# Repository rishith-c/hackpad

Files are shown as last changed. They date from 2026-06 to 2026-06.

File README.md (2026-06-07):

# Hackpad

A 12-key macropad with a rotary encoder and an OLED display, built on a
Seeed XIAO RP2040 and running KMK firmware. Submitted to Hack Club's
[Hackpad](https://hackpad.hackclub.com) You Ship, We Ship program.

**v2** — the most loaded build that fits the Hackpad rules at once:
12 MX keys, 1 EC11 rotary encoder, 1 OLED display, and every usable GPIO
on the XIAO consumed (11 / 11). 13 inputs, well under the 16-input cap;
95 × 95 mm board, well inside the 100 × 100 mm size cap.

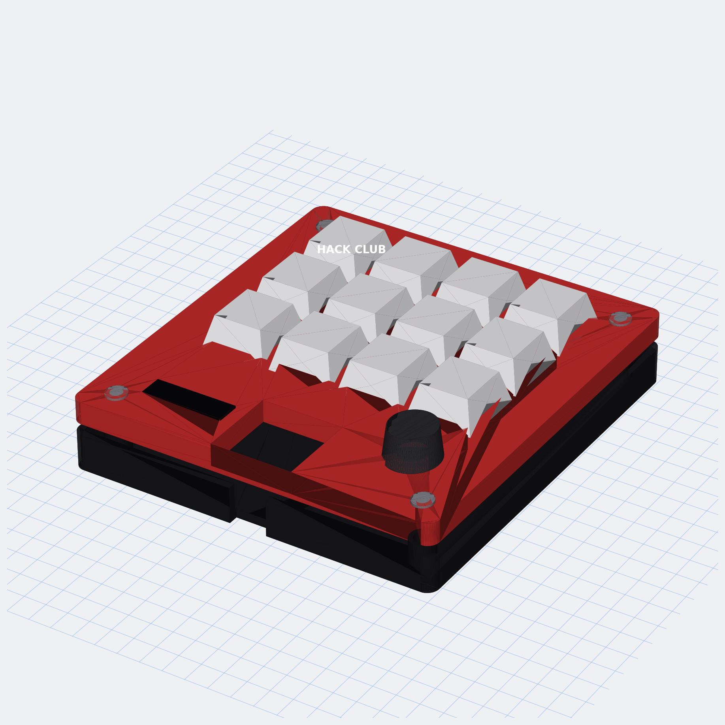
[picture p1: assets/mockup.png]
Assembled mockup


## Features

- **12 MX mechanical switches** in a 4 × 3 diode matrix (COL2ROW, 1N4148)
- **1 EC11 rotary encoder** — defaults to volume +/− (re-mapped per layer)
- **0.91" 128 × 32 SSD1306 OLED** showing the active layer name
- **3 firmware layers** (default / media / numpad), momentary switching
  via the bottom-right key (and bottom-right-2 for L2)
- **Two-part 3D-printed case** (red top plate + black bottom tray),
  M3 heatset insert bosses, USB-C side cutout
- **Individual STL part files** for every printable AND hardware item
  (top, bottom, M3 screws, heatset inserts)

## CAD model

Full assembled view in [`cad/assembled-model.step`](cad/assembled-model.step) —
GitHub renders the STEP inline. STL version in
[`cad/assembled-model.stl`](cad/assembled-model.stl).

Printable + hardware parts (all generated by
[`build_scripts/build_case.py`](build_scripts/build_case.py)):

| Part | STL | STEP | Notes |
|---|---|---|---|
| Top plate (red, 5 mm) | [Top.stl](production/Top.stl) | [Top.step](production/Top.step) | 12 MX cutouts + encoder hole + OLED window + XIAO inspection |
| Bottom tray (black, 8 mm) | [Bottom.stl](production/Bottom.stl) | [Bottom.step](production/Bottom.step) | 4× heatset bosses + USB-C side cutout |
| M3 × 16 mm SHCS screw (×4) | [M3x16_Screw.stl](production/M3x16_Screw.stl) | [M3x16_Screw.step](production/M3x16_Screw.step) | hardware visualization — kit supplies real ones |
| M3 × 5 × 4 mm brass heatset insert (×4) | [HeatsetInsert_M3x5x4.stl](production/HeatsetInsert_M3x5x4.stl) | [HeatsetInsert_M3x5x4.step](production/HeatsetInsert_M3x5x4.step) | hardware visualization — kit supplies real ones |

Case fits within **99 × 99 × 15 mm** — well inside Hackpad's
200 × 200 × 100 mm limit. Screwed together with 4 × M3 × 16 mm SHCS bolts
into M3 × 5 × 4 mm brass heatset inserts.

## PCB

Built in [KiCad 9](https://www.kicad.org/) from
[`pcb/hackpad.kicad_pro`](pcb/hackpad.kicad_pro). The whole board is
generated programmatically by
[`build_scripts/build_pcb.py`](build_scripts/build_pcb.py) from the netlist
+ placement CSVs — re-running it reproduces the `.kicad_pcb` byte-for-byte.

Schematic:

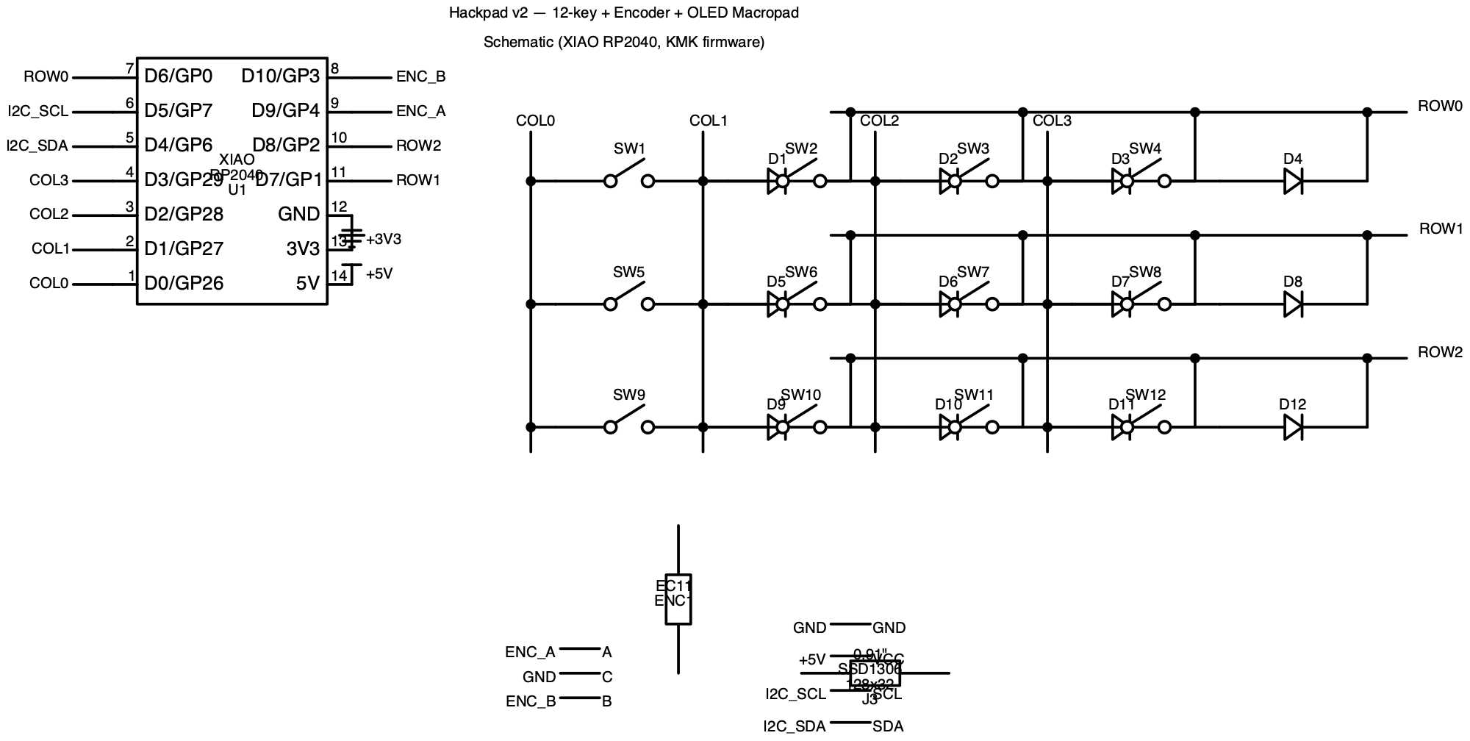
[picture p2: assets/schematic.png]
Schematic


PCB layout (top and bottom copper):

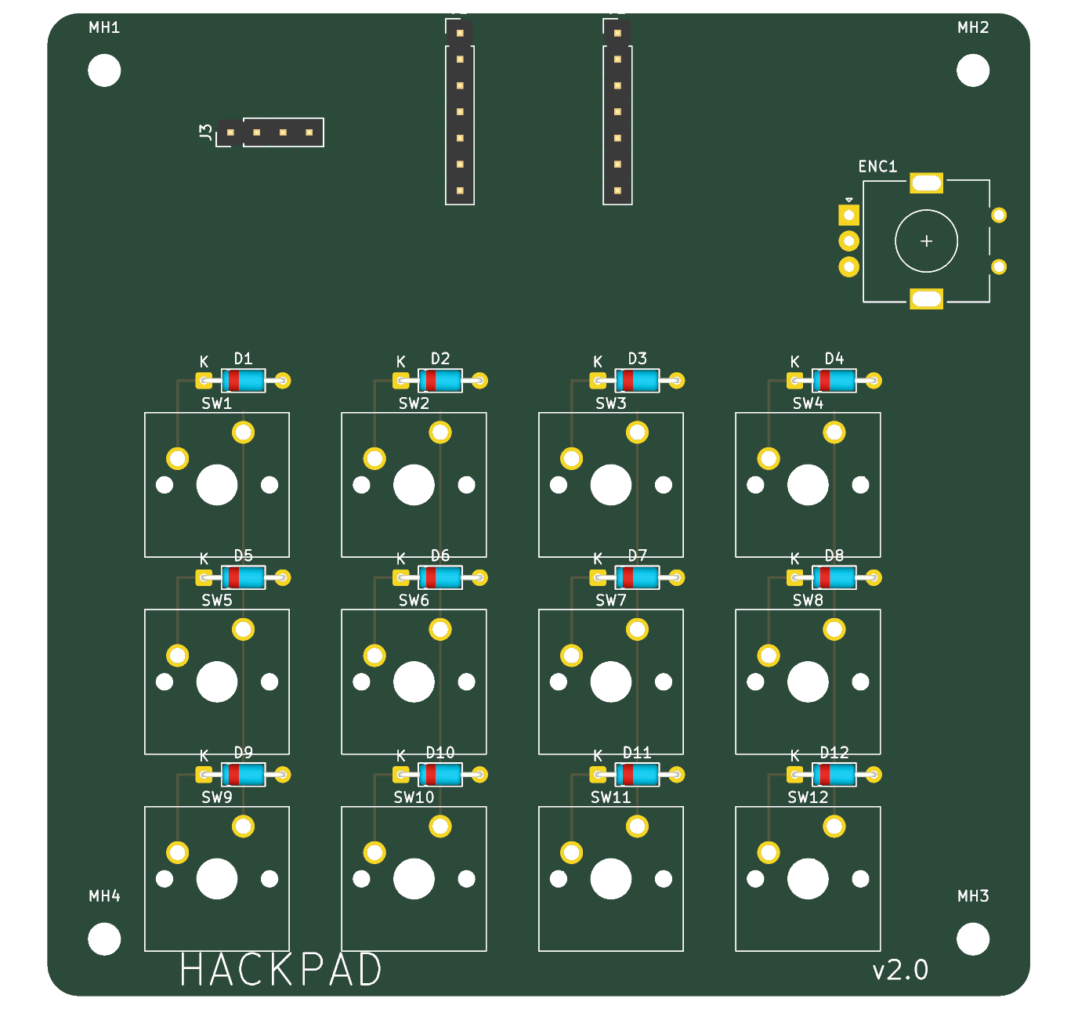
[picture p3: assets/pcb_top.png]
PCB top

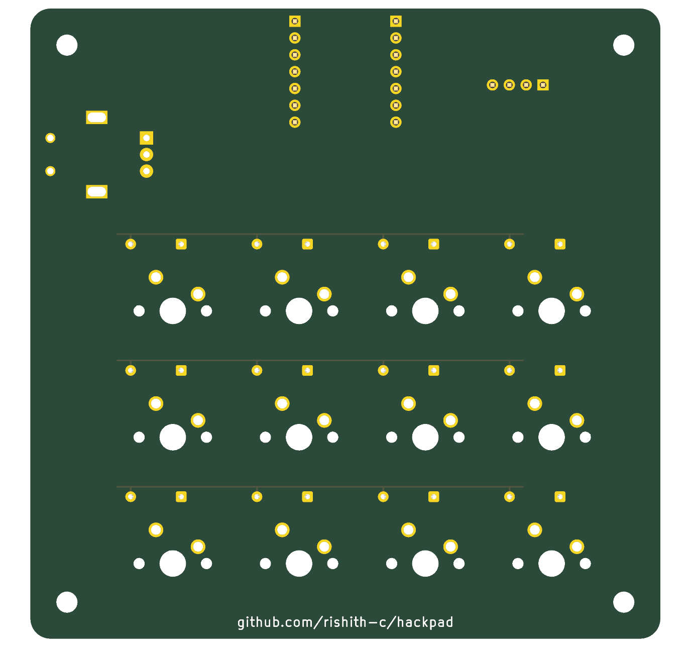
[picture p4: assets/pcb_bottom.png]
PCB bottom


- **Dimensions:** 95 × 95 mm (within the Hackpad 100 × 100 mm rule)
- **Layers:** 2 (F.Cu signal trunks + B.Cu GND pour and ROW trunks)
- **OLED header pin order:** GND – VCC – SCL – SDA (kit spec)
- **Footprints:** Cherry MX 1.00u PCB, 1N4148 DO-35 horizontal,
  EC11E vertical, XIAO on 2 × `PinHeader_1x07_P2.54mm_Vertical`,
  OLED on `PinHeader_1x04_P2.54mm_Vertical`, `MountingHole_3.2mm_M3`
- **Routing:** matrix is fully routed in copper (4 COL trunks F.Cu,
  3 ROW trunks B.Cu with cathode tabs, 12 switch→anode bridges, GND
  pour). 11 short XIAO ↔ peripheral signal pulls (4 COL + 3 ROW + SDA
  + SCL + 5V + ENC_A + ENC_B) are left as ratlines for ~5 min of
  interactive routing — see
  [`pcb/HOW_TO_FINISH.md`](pcb/HOW_TO_FINISH.md) for the exact
  start/end coordinates of each pull.
- **Silkscreen:** `HACKPAD v2.0` on the front, `github.com/rishith-c/hackpad`
  on the back.
- **DRC:** passes at error level
  (`kicad-cli pcb drc --severity-error` → **0 violations**)

Gerbers exported and ready for JLCPCB:
[`production/gerbers.zip`](production/gerbers.zip).
Order at 2 layers · 1.6 mm · HASL · green.

## Firmware

KMK (CircuitPython). See [`firmware/README.md`](firmware/README.md) for
flashing instructions. Sources in [`firmware/KMK/`](firmware/KMK/):

| File | Purpose |
|---|---|
| [`firmware/KMK/main.py`](firmware/KMK/main.py) | 4×3 matrix + encoder + OLED setup, 3 keymap layers |
| [`firmware/KMK/code.py`](firmware/KMK/code.py) | CircuitPython entry point (imports `main`) |
| [`firmware/KMK/boot.py`](firmware/KMK/boot.py) | disables CIRCUITPY auto-reload while plugged in |

## Pin map

The XIAO RP2040 exposes 11 usable GPIO. **All 11 are used.**

| XIAO | GPIO | Role |
|---|---|---|
| D0 | GP26 | matrix COL0 (left column) |
| D1 | GP27 | matrix COL1 |
| D2 | GP28 | matrix COL2 |
| D3 | GP29 | matrix COL3 (right column) |
| D4 | GP6 | OLED SDA (I²C1) |
| D5 | GP7 | OLED SCL (I²C1) |
| D6 | GP0 | matrix ROW0 (top row) |
| D7 | GP1 | matrix ROW1 (middle row) |
| D8 | GP2 | matrix ROW2 (bottom row) |
| D9 | GP4 | encoder phase A |
| D10 | GP3 | encoder phase B |

No spare GPIOs. See [`pcb/DESIGN_NOTES.md`](pcb/DESIGN_NOTES.md) for
alternate firmware tweaks (drop OLED for encoder push + RGB; shrink
matrix to 3×3 for a second encoder; etc.) — each one reuses this same
PCB without changes.

## Bill of Materials

See [`production/BOM.csv`](production/BOM.csv). Everything except the
PLA filament is in the Hackpad kit.

- 1 × Seeed XIAO RP2040 (through-hole, mounts on 2 × 1×7 pin sockets)
- 12 × Cherry MX mechanical switch
- 12 × DSA blank keycap
- 12 × 1N4148 diode (DO-35)
- 1 × EC11 rotary encoder (A/B wired, push left unwired)
- 1 × 0.91" SSD1306 128 × 32 OLED (I²C, addr 0x3C, pin order GND-VCC-SCL-SDA)
- 4 × M3 × 16 mm SHCS bolt
- 4 × M3 × 5 × 4 mm brass heatset insert
- 1 × 3D-printed top plate ([`production/Top.stl`](production/Top.stl))
- 1 × 3D-printed bottom tray ([`production/Bottom.stl`](production/Bottom.stl))

## Repository layout

```
├── README.md
├── LICENSE
├── cad/
│   ├── assembled-model.step              # full assembly (Hackpad spec)
│   └── assembled-model.stl               # same, STL (GitHub interactive viewer)
├── pcb/
│   ├── hackpad.kicad_pro                 # KiCad project
│   ├── hackpad.kicad_sch                 # schematic stub (canonical viz in assets/schematic.png)
│   ├── hackpad.kicad_pcb                 # placed + matrix-routed board
│   ├── netlist.csv                       # canonical net list
│   ├── placement.csv                     # per-part X/Y/rotation
│   ├── DESIGN_NOTES.md                   # build variants / pin budget reasoning
│   └── HOW_TO_FINISH.md                  # 5-min interactive routing checklist
├── firmware/
│   ├── README.md
│   └── KMK/
│       ├── main.py                       # KMK firmware (matrix + encoder + OLED, 3 layers)
│       ├── code.py                       # CircuitPython entry point
│       └── boot.py                       # boot-time config
├── production/
│   ├── gerbers.zip                       # for JLCPCB (2 layers, 1.6 mm)
│   ├── Top.step / Top.stl                # top plate
│   ├── Bottom.step / Bottom.stl          # bottom tray
│   ├── M3x16_Screw.step / .stl           # individual screw model (used x4)
│   ├── HeatsetInsert_M3x5x4.step / .stl  # individual insert model (used x4)
│   ├── main.py                           # KMK production firmware (copy of firmware/KMK/main.py)
│   ├── BOM.csv                           # bill of materials
│   └── HOW_TO_FINISH.md                  # finish-the-routing checklist
├── assets/                               # README screenshots (PCB top/bottom/iso, mockup, schematic)
└── build_scripts/
    ├── build_pcb.py                      # regenerates pcb/hackpad.kicad_pcb via pcbnew
    ├── build_case.py                     # regenerates production STLs + cad/assembled-model via cadquery
    ├── build_schematic.py                # regenerates assets/schematic.{svg,png} via schemdraw
    └── build_mockup.py                   # regenerates assets/mockup.png (and ~/Desktop/) via matplotlib
```

## Submitting to Hackpad

This repo matches the [Hackpad submission requirements](https://hackpad.hackclub.com/submitting):

- PCB ≤ 100 × 100 mm ✅ (this board is 95 × 95 mm)
- < 16 inputs ✅ (13: 12 keys + 1 encoder)
- 2-layer PCB ✅
- Through-hole XIAO RP2040 ✅
- All-3D-printed case ✅
- Folder layout: `cad/`, `pcb/`, `firmware/`, `production/`, `README.md` ✅
  (matches the [Orpheuspad reference](https://github.com/hackclub/hackpad/tree/main/hackpads/orpheuspad))

Submission steps:

1. **Post a ship** in `#hackpad-ships` on the Hack Club Slack (link to
   this repo + photos from `assets/`).
2. **Fill out the submission form**: <https://forms.hackclub.com/hackpad-submission>.
3. Reviewed by `@alexren`. On approval you receive the kit + a $15
   grant for JLCPCB PCB fab + a free 3D-printed case from another
   Hack Clubber, plus optionally $18 for a soldering iron.

## Regenerating from source

```bash
# PCB (uses KiCad 9 bundled Python — pcbnew API)
/Applications/KiCad.app/Contents/Frameworks/Python.framework/Versions/Current/bin/python3 build_scripts/build_pcb.py

# Case + screws + assembled model (pip install cadquery)
python3 build_scripts/build_case.py

# Schematic (pip install schemdraw cairosvg; cairo from Homebrew)
DYLD_FALLBACK_LIBRARY_PATH=/opt/homebrew/lib python3 build_scripts/build_schematic.py

# Mockup PNG (pip install cadquery trimesh matplotlib)
python3 build_scripts/build_mockup.py

# Gerbers + drill files, bundled to production/gerbers.zip
mkdir -p /tmp/gerbers && \
  /Applications/KiCad.app/Contents/MacOS/kicad-cli pcb export gerbers \
    --output /tmp/gerbers/ \
    --layers "F.Cu,B.Cu,F.Silkscreen,B.Silkscreen,F.Mask,B.Mask,Edge.Cuts" \
    pcb/hackpad.kicad_pcb && \
  /Applications/KiCad.app/Contents/MacOS/kicad-cli pcb export drill \
    --output /tmp/gerbers/ --excellon-separate-th pcb/hackpad.kicad_pcb && \
  ( cd /tmp/gerbers && zip /path/to/production/gerbers.zip *.gtl *.gbl *.gto *.gbo *.gts *.gbs *.gm1 *.drl )
```

## License

[MIT](LICENSE).

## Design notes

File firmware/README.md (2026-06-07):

# Firmware

This hackpad runs on **KMK** (CircuitPython). The sources live in [`KMK/`](KMK/):

- [`KMK/main.py`](KMK/main.py) — 4×3 matrix + EC11 encoder + OLED setup, 3 keymap layers
- [`KMK/code.py`](KMK/code.py) — CircuitPython entry point (imports `main`)
- [`KMK/boot.py`](KMK/boot.py) — disables CIRCUITPY auto-reload while plugged in

## Flashing

1. Download **CircuitPython for Seeed XIAO RP2040** from
   <https://circuitpython.org/board/seeeduino_xiao_rp2040/> (the `.uf2`).
2. Double-tap the XIAO BOOT button to enter bootloader mode (a `RPI-RP2`
   drive mounts). Drag the `.uf2` onto it. The XIAO reboots into
   CircuitPython and a `CIRCUITPY` drive appears.
3. Download the latest [KMK firmware](https://github.com/KMKfw/kmk_firmware)
   release zip. Copy the `kmk/` folder from the zip onto `CIRCUITPY`.
4. Copy `main.py`, `code.py`, and `boot.py` from this folder onto
   `CIRCUITPY`.
5. Done. The macropad starts working immediately.

## Default keymap (3 layers, 12 keys per layer)

Layer layout (matrix index = row × 4 + col):

| Row | Col 0 | Col 1 | Col 2 | Col 3 |
|---|---|---|---|---|
| 0 (top) | SW1  | SW2  | SW3  | SW4  |
| 1 (middle) | SW5  | SW6  | SW7  | SW8  |
| 2 (bottom) | SW9  | SW10 | SW11 | SW12 |

### Layer 0 — Default (letters)

| | | | |
|---|---|---|---|
| A | B | C | D |
| E | F | G | H |
| I | J | K | **MO(1)** (hold for L1) |

Encoder: turn = volume +/−, push: unwired.

### Layer 1 — Media

| | | | |
|---|---|---|---|
| Mute | Play/Pause | Next | Prev |
| Vol+ | Vol−  | — | — |
| — | — | **MO(2)** (hold for L2) | — (passthrough) |

Encoder: turn = next/prev track.

### Layer 2 — Numpad

| | | | |
|---|---|---|---|
| 7 | 8 | 9 | + |
| 4 | 5 | 6 | − |
| 1 | 2 | 3 | — (passthrough) |

Encoder: turn = numpad + / −.

Edit `keyboard.keymap` and `encoder_handler.map` in [`KMK/main.py`](KMK/main.py)
to change.

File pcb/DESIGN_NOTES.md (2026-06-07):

# Design notes

## Why a 12-key + encoder + OLED build

The Hack Club Hackpad submission allows **less than 16 inputs** and a
**≤ 100 × 100 mm** PCB. The XIAO RP2040 exposes **11 usable GPIO**. This
build hits the most loaded point in that 3-way constraint:

- **12 MX keys** (4 cols × 3 rows matrix, 7 pins)
- **1 EC11 rotary encoder** (A/B only, no push — 2 pins)
- **1 0.91" OLED** display (I²C, 2 pins)
- **= 13 inputs · 11 / 11 GPIO · 95 × 95 mm**

That's every kind of input the kit ships in the densest configuration the
rules allow. (The 16-key full numpad designs are at the edge of the input
limit and have no room for an encoder; the orpheuspad-style 4-key builds
have lots of free GPIO but few keys.)

## Pin budget

| Peripheral | Pins | Which GPIOs |
|---|---|---|
| 4×3 matrix | 7 | D0–D3 (COL0..3) + D6–D8 (ROW0..2) |
| EC11 encoder (A, B) | 2 | D9, D10 |
| OLED I²C (SDA, SCL) | 2 | D4, D5 |
| **Total** | **11 / 11** | every usable GPIO consumed |

D9 (GP4) was the spare in v1; v2 spends it on the encoder.

## Alternate firmware tweaks (no PCB change needed)

The pin map is broken out on the XIAO socket, so you can repurpose without
re-fabbing the board — just flash a different `firmware/KMK/main.py`:

### 14 inputs (drop OLED, add encoder push + RGB)

Wire the SK6812 chain off **D10** (currently ENC_B) and the encoder push
button off **D4** (currently SDA). Rebuild firmware to drop the OLED and
add `EncoderHandler` with a button pin. You give up the layer-name
display, gain a click+rotate + RGB underglow.

### 9 keys + 2 encoders + OLED

Shrink the matrix to a 3×3 (uses D0–D2 + D6–D8 = 6 pins), wire encoder 2
across **D3** and **D9**, keep OLED. 10 inputs but two knobs.

## ROW trunk offset trick (carried over from v1)

To keep the B.Cu row trunk from shorting through other columns' diode
anode pads, the trunk is offset **1.5 mm above** the pad row, with a
short 1.5 mm vertical tab from each cathode pad up to the trunk. The
anode pads end up 1.5 mm away from the trunk centerline — comfortably
outside the 0.2 mm clearance limit. See [build_pcb.py](../build_scripts/build_pcb.py)
`_route_matrix()`.

## OLED pin order

The Hack Club kit OLED uses **GND – VCC – SCL – SDA**. This board's
J3 header (rotated 90°) matches that order on pads 1–4.

## RGB

No SK6812 on the PCB — every GPIO is taken. Hand-wire a few LEDs off
the unused side of the encoder pad if you want underglow; firmware does
not enable RGB by default.

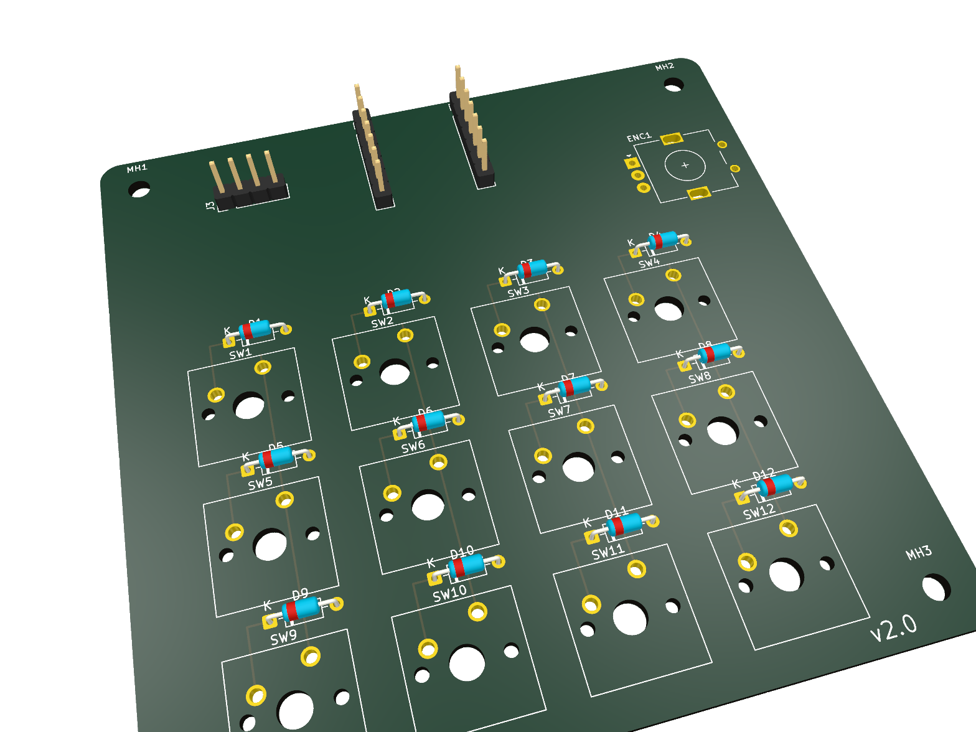
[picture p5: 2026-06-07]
assets/pcb_iso.png

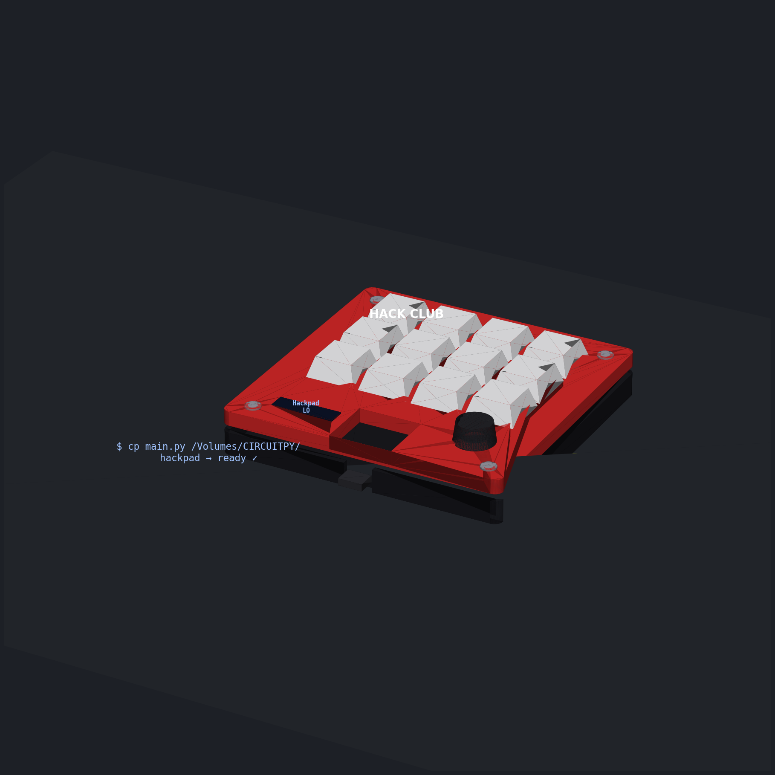
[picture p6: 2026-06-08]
assets/hero.png

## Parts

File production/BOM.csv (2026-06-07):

ref | part | value | qty | source | footprint | notes
U1 | Seeed XIAO RP2040 | RP2040 | 1 | Hackpad kit | XIAO_2x1x7_PinHeader | through-hole MCU on 2x 1x7 sockets
SW1-SW12 | MX mechanical switch | MX | 12 | Hackpad kit (12/16 used) | SW_Cherry_MX_1.00u_PCB | 4x3 matrix at 19.05 mm pitch
KEYCAP | DSA blank keycap (white) | DSA | 12 | Hackpad kit (12/16 used) | n/a | one per switch
D1-D12 | Diode | 1N4148 (DO-35) | 12 | Hackpad kit (12/20 used) | D_DO-35_SOD27_P7.62mm_Horizontal | COL2ROW; cathode stripe toward row trace
ENC1 | Rotary encoder | Alps EC11 (no push wired) | 1 | Hackpad kit (1/2 used) | RotaryEncoder_Alps_EC11E_Vertical_H20mm | A/B phases + C (GND)
OLED1 | OLED display | SSD1306 128x32 (0.91") | 1 | Hackpad kit | Conn_01x04 (GND-VCC-SCL-SDA) | I2C addr 0x3C
LED (optional) | Addressable RGB | SK6812 MINI-E | 0 | Hackpad kit | n/a | not used (all 11 GPIO are consumed)
MH1-MH4 | Mounting hole | M3 clearance | 4 | n/a | MountingHole_3.2mm_M3 | corner hole pattern (+/-42 +/-42)
SCREW | Socket head screw | M3x16 | 4 | Hackpad kit (4/6 used) | n/a | top plate into bottom-tray heatset inserts; STL: production/M3x16_Screw.stl
INSERT | Brass heatset insert | M3x5x4 | 4 | Hackpad kit (4/6 used) | n/a | melt into bottom-tray bosses (4.0 mm pilot); STL: production/HeatsetInsert_M3x5x4.stl
CASE_TOP | 3D-printed top plate | PLA/PETG | 1 | production/Top.stl | n/a | 12 MX cutouts + encoder hole + OLED window + XIAO inspection
CASE_BOTTOM | 3D-printed bottom tray | PLA/PETG | 1 | production/Bottom.stl | n/a | 4x M3 heatset bosses + USB-C side cutout

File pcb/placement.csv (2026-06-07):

ref | part | x_mm | y_mm | rotation_deg
SW1 | MX switch (row 0 col 0) | -28.575 | -7.0 | 0
D1 | 1N4148 diode | -32.385 | -12.0 | 0
SW2 | MX switch (row 0 col 1) | -9.525 | -7.0 | 0
D2 | 1N4148 diode | -13.335 | -12.0 | 0
SW3 | MX switch (row 0 col 2) | 9.525 | -7.0 | 0
D3 | 1N4148 diode | 5.715 | -12.0 | 0
SW4 | MX switch (row 0 col 3) | 28.575 | -7.0 | 0
D4 | 1N4148 diode | 24.765 | -12.0 | 0
SW5 | MX switch (row 1 col 0) | -28.575 | 12.05 | 0
D5 | 1N4148 diode | -32.385 | 7.05 | 0
SW6 | MX switch (row 1 col 1) | -9.525 | 12.05 | 0
D6 | 1N4148 diode | -13.335 | 7.05 | 0
SW7 | MX switch (row 1 col 2) | 9.525 | 12.05 | 0
D7 | 1N4148 diode | 5.715 | 7.05 | 0
SW8 | MX switch (row 1 col 3) | 28.575 | 12.05 | 0
D8 | 1N4148 diode | 24.765 | 7.05 | 0
SW9 | MX switch (row 2 col 0) | -28.575 | 31.1 | 0
D9 | 1N4148 diode | -32.385 | 26.1 | 0
SW10 | MX switch (row 2 col 1) | -9.525 | 31.1 | 0
D10 | 1N4148 diode | -13.335 | 26.1 | 0
SW11 | MX switch (row 2 col 2) | 9.525 | 31.1 | 0
D11 | 1N4148 diode | 5.715 | 26.1 | 0
SW12 | MX switch (row 2 col 3) | 28.575 | 31.1 | 0
D12 | 1N4148 diode | 24.765 | 26.1 | 0
J1 | XIAO header left (1x07) | -7.62 | -45.62 | 0
J2 | XIAO header right (1x07) | 7.62 | -45.62 | 0
J3 | OLED 4-pin header | -29.81 | -36.0 | 90
ENC1 | EC11 rotary encoder | 30 | -28 | 0
MH1 | M3 mounting hole | -42 | -42 | 0
MH2 | M3 mounting hole | 42 | -42 | 0
MH3 | M3 mounting hole | 42 | 42 | 0
MH4 | M3 mounting hole | -42 | 42 | 0

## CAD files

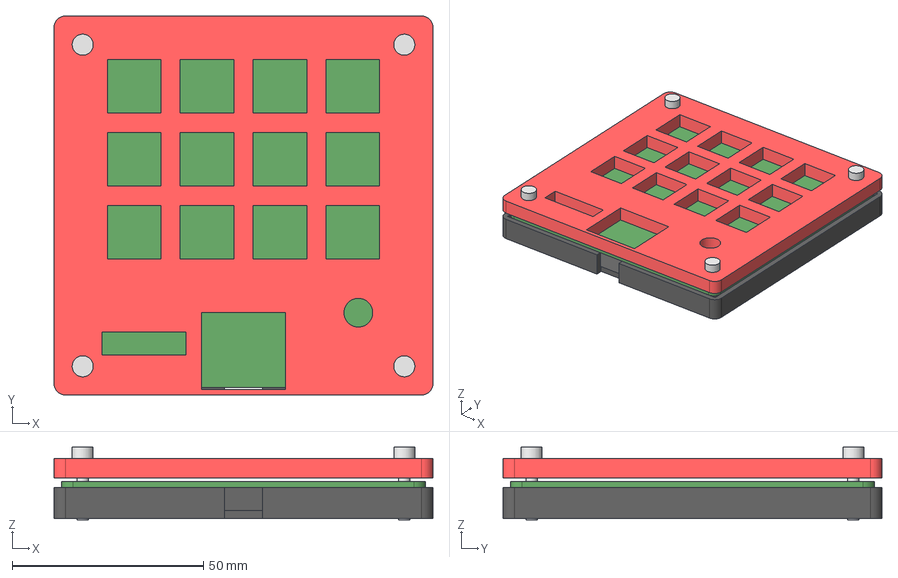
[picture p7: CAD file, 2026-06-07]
cad/assembled-model.step
99.0 x 99.0 x 19.0 mm
bottom
pcb
top
insert1
insert2
insert3
insert4
screw1
screw2
screw3
screw4

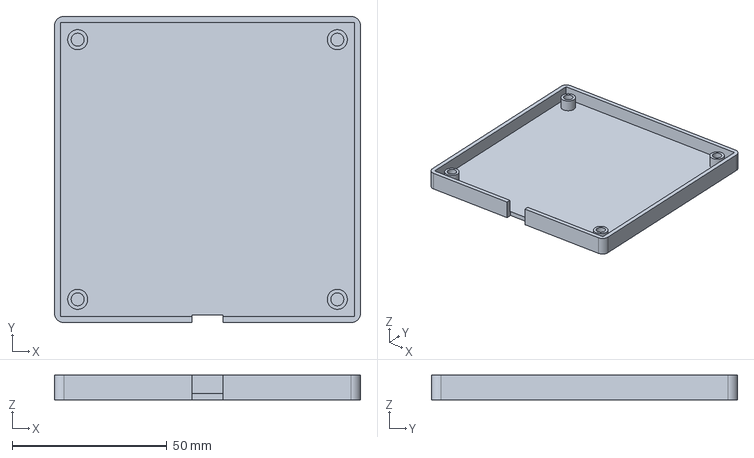
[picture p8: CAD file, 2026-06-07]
production/Bottom.step
99.0 x 99.0 x 8.00 mm

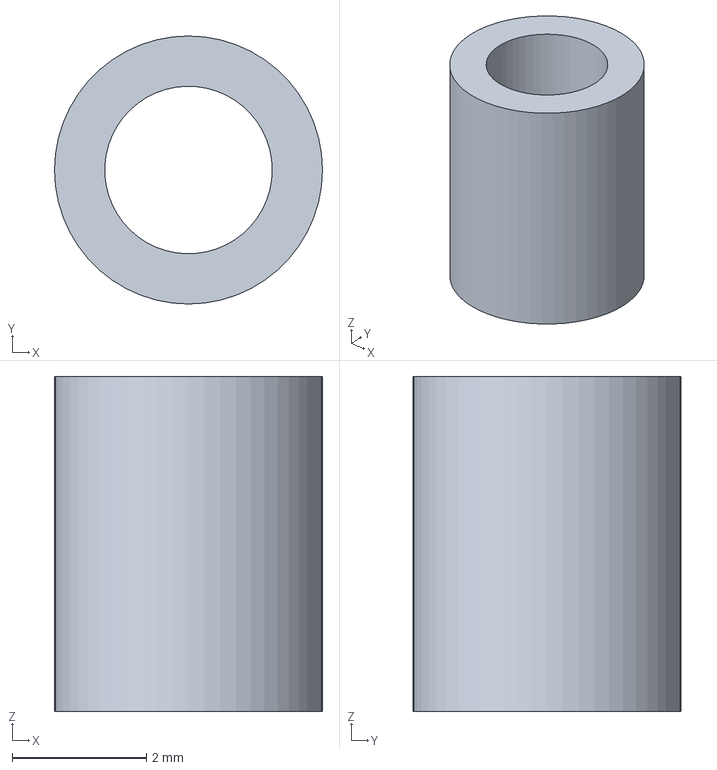
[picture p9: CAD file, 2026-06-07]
production/HeatsetInsert_M3x5x4.step
4.00 x 4.00 x 5.00 mm

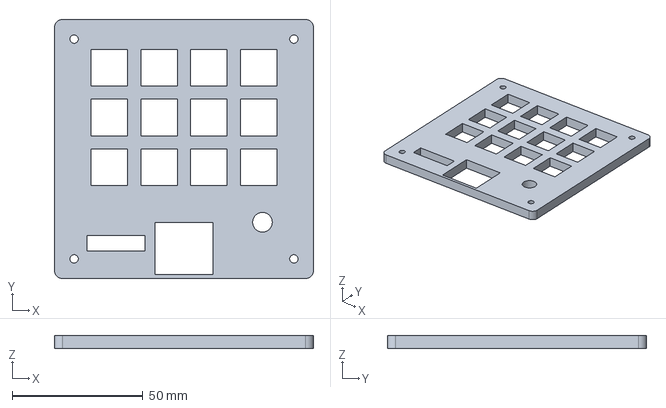
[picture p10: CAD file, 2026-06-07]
production/Top.step
99.0 x 99.0 x 5.00 mm

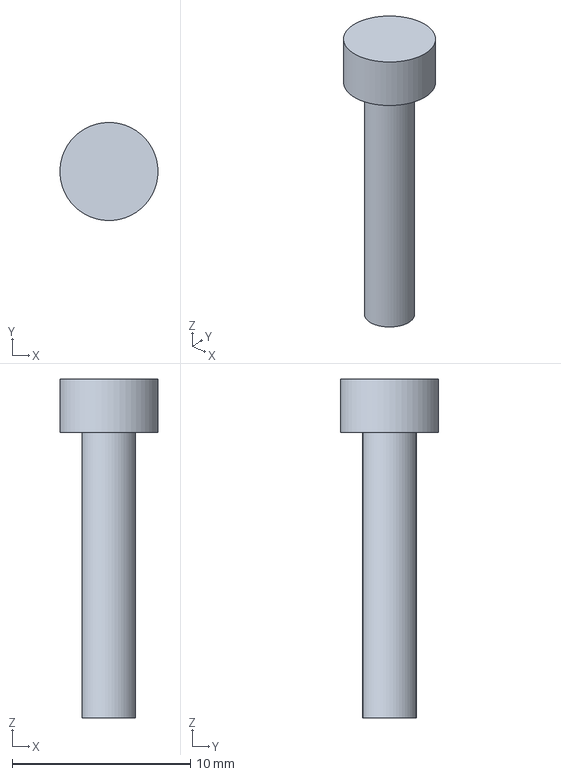
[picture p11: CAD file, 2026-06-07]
production/M3x16_Screw.step
5.49 x 5.50 x 19.0 mm

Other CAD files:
cad/assembled-model.stl
production/Bottom.stl
production/HeatsetInsert_M3x5x4.stl
production/M3x16_Screw.stl
production/Top.stl

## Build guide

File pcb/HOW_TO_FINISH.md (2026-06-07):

# HOW TO FINISH: 11 trace pulls in KiCad

The `.kicad_pro`, `.kicad_sch`, and `.kicad_pcb` are all included, the
12-key matrix is fully routed in copper, and `production/gerbers.zip` was
exported directly from this `.kicad_pcb` — DRC passes at error level. **The
board will fab as-is, but the connections below need to be pulled in KiCad
before the board will actually do anything past the matrix.**

If you'd rather regenerate everything: re-run
[`build_scripts/build_pcb.py`](../build_scripts/build_pcb.py) with KiCad 9's
bundled Python.

## What's already routed (don't touch)

- 12 MX switches + 12 1N4148 diodes placed in a 4×3 grid (19.05 mm pitch).
- COL0..COL3 trunks on **F.Cu** (vertical, one per column, from Y = −9 down
  through every switch in the column).
- ROW0..ROW2 trunks on **B.Cu** (horizontal, 1.5 mm above the diode pad row)
  with short cathode-to-trunk tabs.
- Switch pad B → diode anode bridges on **F.Cu** (short L behind each switch).
- Edge cuts: 95 × 95 mm rounded rectangle, 3 mm corner radius.
- GND pour on **B.Cu** with thermal reliefs — auto-connects every GND pad.
- M3 mounting holes at (±42, ±42).
- XIAO socket: two `PinHeader_1x07_P2.54mm_Vertical` at X = ±7.62, top-center,
  USB-C facing the top edge.
- OLED socket: `PinHeader_1x04_P2.54mm_Vertical` rotated 90°, GND end at
  (−29.81, −36). Pad order from −X to +X: GND, VCC, SCL, SDA.
- EC11 rotary encoder at (30, −28). Pads A, C(GND), B sit at X = 30,
  Y = −28 / −25.5 / −23. C (common) is already on the GND pour.
- Silkscreen branding ("HACKPAD" v2.0 on the front, repo URL on the back).

## What you finish in KiCad (11 traces, ~5 min)

Open [`pcb/hackpad.kicad_pcb`](hackpad.kicad_pcb). Switch to
**Route > Single Track** (`X`). Default trace width is 0.25 mm for
signals, 0.5 mm for power.

| # | Net | From (XIAO pin) | To | Notes |
|---|---|---|---|---|
| 1 | COL0 | J1 pad 1 — (−7.62, −45.62) | Top of COL0 trunk — (−28.575, −9) | F.Cu, longest fanout |
| 2 | COL1 | J1 pad 2 — (−7.62, −43.08) | Top of COL1 trunk — (−9.525, −9) | F.Cu |
| 3 | COL2 | J1 pad 3 — (−7.62, −40.54) | Top of COL2 trunk — (9.525, −9) | F.Cu, must dodge XIAO right pins |
| 4 | COL3 | J1 pad 4 — (−7.62, −38.00) | Top of COL3 trunk — (28.575, −9) | F.Cu, must dodge XIAO right pins + encoder |
| 5 | I2C_SDA | J1 pad 5 — (−7.62, −35.46) | OLED pad 4 — (−22.19, −36) | F.Cu, short hop left |
| 6 | I2C_SCL | J1 pad 6 — (−7.62, −32.92) | OLED pad 3 — (−24.73, −36) | F.Cu, parallel to SDA |
| 7 | ROW0 | J1 pad 7 — (−7.62, −30.38) | Left end of ROW0 trunk — (−26.765, −13.5) | B.Cu via at pin; cleanest on B.Cu under everything |
| 8 | ROW1 | J2 pad 4 — (7.62, −38.00) | Right end of ROW1 trunk — (34.385, 5.55) | B.Cu via at pin; route through right gutter |
| 9 | ROW2 | J2 pad 3 — (7.62, −40.54) | Right end of ROW2 trunk — (34.385, 24.6) | B.Cu, right gutter, different lane than ROW1 |
| 10 | ENC_A | J2 pad 2 — (7.62, −43.08) | Encoder pad A — (30, −28) | F.Cu, short hop right |
| 11 | ENC_B | J2 pad 1 — (7.62, −45.62) | Encoder pad B — (30, −23) | F.Cu, parallel to ENC_A |
| 12 | VCC_5V | J2 pad 7 — (7.62, −30.38) | OLED pad 2 — (−27.27, −36) | **F.Cu, 0.5 mm wide**, runs across the top |

**GND** (XIAO J2 pad 5 → OLED J3 pad 1 → encoder C) connects automatically
through the B.Cu GND pour's thermal reliefs.

### Tips

- The XIAO header pads are THT, so you can start a B.Cu trace right at the
  pad without a via — the pad already exists on both layers.
- All COL fanout traces (1–4) live in the F.Cu space between the XIAO bottom
  (Y ≈ −30) and the COL trunk tops (Y = −9). That's ~20 mm of clear lane;
  pick a separate Y lane per column to keep them parallel.
- ROW1 and ROW2 should use the right gutter (around X = 40–42, between the
  matrix's right edge at X ≈ 35 and the right mounting hole at X = 42).
- Place ENC_A and ENC_B on F.Cu before routing the VCC_5V trace — VCC_5V
  is fatter (0.5 mm) and will block them otherwise.

## After routing

```bash
# In KiCad GUI:
#   Inspect > Design Rules Checker > Run DRC (0 errors, 0 unconnected)
#   File > Fabrication Outputs > Gerbers... → output to a fresh folder
#   File > Fabrication Outputs > Drill Files... → same folder
#   zip the .gbr + .drl files as gerbers.zip → drop in production/

# OR from the CLI (replaces production/gerbers.zip):
mkdir -p /tmp/gerbers && \
  /Applications/KiCad.app/Contents/MacOS/kicad-cli pcb export gerbers \
    --output /tmp/gerbers/ \
    --layers "F.Cu,B.Cu,F.Silkscreen,B.Silkscreen,F.Mask,B.Mask,Edge.Cuts" \
    pcb/hackpad.kicad_pcb && \
  /Applications/KiCad.app/Contents/MacOS/kicad-cli pcb export drill \
    --output /tmp/gerbers/ --excellon-separate-th pcb/hackpad.kicad_pcb && \
  ( cd /tmp/gerbers && zip /path/to/production/gerbers.zip *.gtl *.gbl *.gto *.gbo *.gts *.gbs *.gm1 *.drl )
```

## JLCPCB order (covered by the Hackpad $15 grant)

2 layers · 1.6 mm · qty 5 · HASL · green (cheapest). Upload `gerbers.zip`,
preview, order. **Get the design approved by Hack Club first** so the grant applies.

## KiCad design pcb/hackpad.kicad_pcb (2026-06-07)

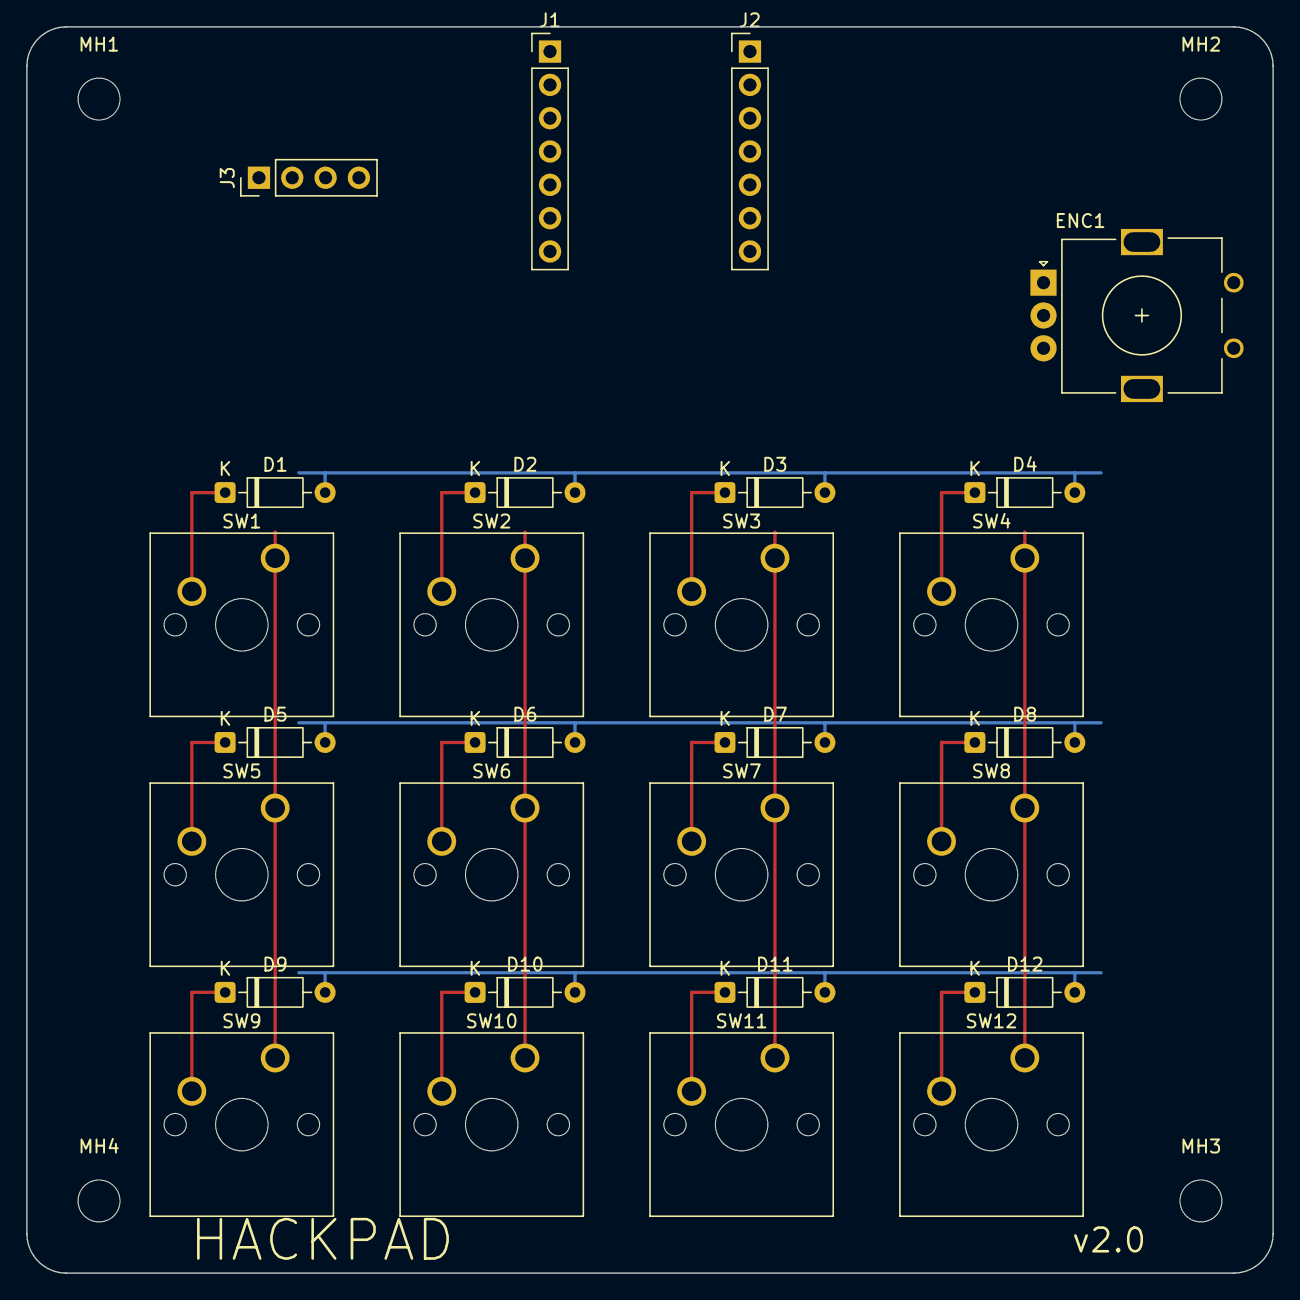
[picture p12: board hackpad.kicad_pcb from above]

Board: 2 copper layers, 95.0 x 95.0 mm, 32 parts (0 on the bottom side), 25 nets.

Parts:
D1, D2, D3, D4, D5, D6, D7, D8, D9, D10, D11, D12: 1N4148; D_DO-35_SOD27_P7.62mm_Horizontal
ENC1: EC11; RotaryEncoder_Alps_EC11E_Vertical_H20mm
J1: XIAO_L; PinHeader_1x07_P2.54mm_Vertical
J2: XIAO_R; PinHeader_1x07_P2.54mm_Vertical
J3: OLED; PinHeader_1x04_P2.54mm_Vertical
MH1, MH2, MH3, MH4: M3; MountingHole_3.2mm_M3
SW1, SW2, SW3, SW4, SW5, SW6, SW7, SW8, SW9, SW10, SW11, SW12: MX; SW_Cherry_MX_1.00u_PCB

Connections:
COL0: J1.1, SW1.1, SW5.1, SW9.1
COL1: J1.2, SW2.1, SW6.1, SW10.1
COL2: J1.3, SW3.1, SW7.1, SW11.1
COL3: J1.4, SW4.1, SW8.1, SW12.1
ENC_A: ENC1.A, J2.2
ENC_B: ENC1.B, J2.1
GND: ENC1.C, J2.5, J3.1
I2C_SCL: J1.6, J3.3
I2C_SDA: J1.5, J3.4
ROW0: D1.2, D2.2, D3.2, D4.2, J1.7
ROW1: D5.2, D6.2, D7.2, D8.2, J2.4
ROW2: D9.2, D10.2, D11.2, D12.2, J2.3
SW1_K: D1.1, SW1.2
SW2_K: D2.1, SW2.2
SW3_K: D3.1, SW3.2
SW4_K: D4.1, SW4.2
SW5_K: D5.1, SW5.2
SW6_K: D6.1, SW6.2
SW7_K: D7.1, SW7.2
SW8_K: D8.1, SW8.2
SW9_K: D9.1, SW9.2
SW10_K: D10.1, SW10.2
SW11_K: D11.1, SW11.2
SW12_K: D12.1, SW12.2
VCC_5V: J2.7, J3.2

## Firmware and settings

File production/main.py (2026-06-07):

"""Hackpad firmware - 12-key macropad (4x3 matrix) + EC11 encoder + OLED.

Runs on KMK (CircuitPython) on a Seeed XIAO RP2040.
Flash CircuitPython for XIAO RP2040, copy the kmk/ library to the drive,
then drop this file as `code.py` (or `main.py`).

Pin map (all 11 GPIO used):
  D0  GP26 = COL0      D6  GP0  = ROW0
  D1  GP27 = COL1      D7  GP1  = ROW1
  D2  GP28 = COL2      D8  GP2  = ROW2
  D3  GP29 = COL3      D9  GP4  = ENC_A
  D4  GP6  = I2C SDA   D10 GP3  = ENC_B
  D5  GP7  = I2C SCL

Matrix is 4 columns × 3 rows = 12 keys, COL2ROW (1N4148 diodes,
cathode-stripe toward the row trace).
"""

import board

from kmk.kmk_keyboard import KMKKeyboard
from kmk.keys import KC
from kmk.matrix import DiodeOrientation
from kmk.modules.layers import Layers
from kmk.modules.encoder import EncoderHandler

keyboard = KMKKeyboard()
keyboard.modules.append(Layers())

# ---- 4×3 matrix --------------------------------------------------------
keyboard.col_pins = (board.D0, board.D1, board.D2, board.D3)   # COL0..COL3
keyboard.row_pins = (board.D6, board.D7, board.D8)             # ROW0..ROW2
keyboard.diode_orientation = DiodeOrientation.COL2ROW

# Keymap layout: 3 rows × 4 cols = 12 keys per layer.
keyboard.keymap = [
    [
        # Layer 0 — app shortcuts
        KC.A,   KC.B,   KC.C,   KC.D,
        KC.E,   KC.F,   KC.G,   KC.H,
        KC.I,   KC.J,   KC.K,   KC.MO(1),    # bottom-right = hold layer 1
    ],
    [
        # Layer 1 — media controls
        KC.MUTE,  KC.MPLY,  KC.MNXT,  KC.MPRV,
        KC.VOLU,  KC.VOLD,  KC.NO,    KC.NO,
        KC.NO,    KC.NO,    KC.MO(2), KC.TRNS,
    ],
    [
        # Layer 2 — numpad (tap-tap from layer 0 → layer 1 → layer 2)
        KC.N7, KC.N8, KC.N9, KC.PLUS,
        KC.N4, KC.N5, KC.N6, KC.MINS,
        KC.N1, KC.N2, KC.N3, KC.TRNS,
    ],
]

# ---- Rotary encoder ----------------------------------------------------
encoder_handler = EncoderHandler()
keyboard.modules.append(encoder_handler)
# (pin_a, pin_b, button_pin_or_None, is_inverted)
encoder_handler.pins = (
    (board.D9, board.D10, None, False),
)
# Per-layer encoder map: (clockwise, counter-clockwise)
encoder_handler.map = [
    ((KC.VOLU, KC.VOLD),),       # layer 0 — volume
    ((KC.MNXT, KC.MPRV),),       # layer 1 — track skip
    ((KC.PPLS, KC.PMNS),),       # layer 2 — numpad + / -
]

# ---- OLED display (optional; skipped if not connected) ----------------
try:
    import busio
    from kmk.extensions.display import Display, TextEntry
    from kmk.extensions.display.ssd1306 import SSD1306
    i2c_bus = busio.I2C(board.D5, board.D4)   # SCL=D5, SDA=D4
    display = Display(
        display=SSD1306(i2c_bus, device_address=0x3C),
        entries=[
            TextEntry(text="Hackpad", x=0, y=0),
            TextEntry(text="L0 default",   x=0, y=16, layer=0),
            TextEntry(text="L1 media",     x=0, y=16, layer=1),
            TextEntry(text="L2 numpad",    x=0, y=16, layer=2),
        ],
        brightness=0.5,
    )
    keyboard.extensions.append(display)
except Exception:   # noqa: BLE001
    # No display attached — keep running.
    pass


if __name__ == "__main__":
    keyboard.go()

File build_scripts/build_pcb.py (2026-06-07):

#!/usr/bin/env python3
"""Build the Hackpad KiCad PCB programmatically with pcbnew.

Design: 12-key macropad (4x3 matrix) + EC11 rotary encoder + 0.91" OLED on a
Seeed XIAO RP2040 - maxes out the kit/rules without going over:
  - PCB <= 100mm x 100mm (this is 95 x 95 mm)
  - < 16 inputs (12 keys + 1 encoder = 13 inputs)
  - 2 layers, through-hole XIAO RP2040
  - OLED pin order: GND - VCC - SCL - SDA (kit standard)

Layout (board origin = center; KiCad +Y is downward):
  - XIAO at top-center (0, -38), USB-C faces top edge
  - OLED 4-pin header at top-left (-26, -36) (rotated 90, pads along +X)
  - EC11 rotary encoder at top-right (30, -28)
  - 4x3 matrix below (12 MX switches) — rows Y = -7, +12.05, +31.1
  - 4 M3 mounting holes at (+/-42, +/-42)

Pin map (XIAO RP2040) — all 11 GPIO used:
   D0 (GP26) = COL0     D6 (GP0)  = ROW0
   D1 (GP27) = COL1     D7 (GP1)  = ROW1
   D2 (GP28) = COL2     D8 (GP2)  = ROW2
   D3 (GP29) = COL3     D9 (GP4)  = ENC_A
   D4 (GP6)  = I2C_SDA  D10 (GP3) = ENC_B
   D5 (GP7)  = I2C_SCL
"""

import os

import pcbnew
from pcbnew import (
    BOARD, NETINFO_ITEM, PCB_SHAPE, PCB_TRACK, PCB_VIA, VECTOR2I, ZONE,
)

ROOT = os.path.abspath(os.path.join(os.path.dirname(__file__), ".."))
PCB_DIR = os.path.join(ROOT, "pcb")
KICAD_FP_ROOT = "/Applications/KiCad.app/Contents/SharedSupport/footprints"

PROJECT_NAME = "hackpad"
PCB_PATH = os.path.join(PCB_DIR, f"{PROJECT_NAME}.kicad_pcb")

# ---- design constants ----
BOARD_W_MM = 95.0
BOARD_H_MM = 95.0
BOARD_CORNER_R_MM = 3.0
TRACK_SIG_MM = 0.25
TRACK_PWR_MM = 0.5
VIA_DRILL_MM = 0.4
VIA_DIA_MM = 0.8
CLEARANCE_MM = 0.2

# Matrix grid (KiCad mm)
SW_PITCH = 19.05
NCOL = 4
NROW = 3
SW_X = [-28.575, -9.525, 9.525, 28.575]               # 4 columns
SW_Y = [-7.0, 12.05, 31.1]                            # 3 rows (19.05 mm pitch)
DIODE_DY = -5.0                                        # diode origin offset from switch (above)

OLED_XY = (-26.0, -36.0)
XIAO_XY = (0.0, -38.0)
ENC_XY  = (30.0, -28.0)
MOUNT_HOLES = [(-42.0, -42.0), (42.0, -42.0), (42.0, 42.0), (-42.0, 42.0)]

_IO = pcbnew.PCB_IO_KICAD_SEXPR()


def mm(x):
    return pcbnew.FromMM(x)


def vp(x_mm, y_mm):
    return VECTOR2I(mm(x_mm), mm(y_mm))


def load_footprint(lib, name):
    fp = _IO.FootprintLoad(os.path.join(KICAD_FP_ROOT, f"{lib}.pretty"), name)
    if fp is None:
        raise RuntimeError(f"Footprint not found: {lib}:{name}")
    return fp


def add_footprint(board, lib, name, ref, value, x_mm, y_mm, rot_deg=0.0):
    fp = load_footprint(lib, name)
    fp.SetReference(ref)
    fp.SetValue(value)
    fp.SetPosition(vp(x_mm, y_mm))
    if rot_deg:
        fp.SetOrientationDegrees(rot_deg)
    board.Add(fp)
    return fp


def ensure_net(board, name):
    existing = board.FindNet(name)
    if existing is not None and existing.GetNetCode() > 0:
        return existing
    n = NETINFO_ITEM(board, name)
    board.Add(n)
    return n


def pad_by_name(fp, pad_name):
    for p in fp.Pads():
        if p.GetName() == pad_name:
            return p
    raise RuntimeError(f"{fp.GetReference()} has no pad {pad_name}")


def pad_xy(fp, name):
    p = pad_by_name(fp, name).GetPosition()
    return (pcbnew.ToMM(p.x), pcbnew.ToMM(p.y))


def connect_pad(fp, pad_name, net):
    pad_by_name(fp, pad_name).SetNet(net)


def add_track(board, p1, p2, net, layer=pcbnew.F_Cu, width=TRACK_SIG_MM):
    if p1 == p2:
        return None
    t = PCB_TRACK(board)
    t.SetStart(vp(*p1))
    t.SetEnd(vp(*p2))
    t.SetLayer(layer)
    t.SetWidth(mm(width))
    t.SetNet(net)
    board.Add(t)
    return t


def add_path(board, pts, net, layer=pcbnew.F_Cu, width=TRACK_SIG_MM):
    for a, b in zip(pts, pts[1:]):
        add_track(board, a, b, net, layer, width)


def add_rounded_rect_outline(board, w, h, r):
    hw, hh = w / 2.0, h / 2.0
    for a, b in [
        ((-hw + r, -hh), (hw - r, -hh)),
        ((-hw + r, hh), (hw - r, hh)),
        ((-hw, -hh + r), (-hw, hh - r)),
        ((hw, -hh + r), (hw, hh - r)),
    ]:
        s = PCB_SHAPE(board)
        s.SetShape(pcbnew.SHAPE_T_SEGMENT)
        s.SetStart(vp(*a))
        s.SetEnd(vp(*b))
        s.SetLayer(pcbnew.Edge_Cuts)
        s.SetWidth(mm(0.1))
        board.Add(s)
    for center, start, end in [
        ((-hw + r, -hh + r), (-hw, -hh + r), (-hw + r, -hh)),
        ((hw - r, -hh + r),  (hw - r, -hh),  (hw, -hh + r)),
        ((hw - r, hh - r),   (hw, hh - r),   (hw - r, hh)),
        ((-hw + r, hh - r),  (-hw + r, hh),  (-hw, hh - r)),
    ]:
        a = PCB_SHAPE(board)
        a.SetShape(pcbnew.SHAPE_T_ARC)
        a.SetCenter(vp(*center))
        a.SetStart(vp(*start))
        a.SetEnd(vp(*end))
        a.SetLayer(pcbnew.Edge_Cuts)
        a.SetWidth(mm(0.1))
        board.Add(a)


def add_gnd_zone(board, gnd_net, layer, w, h):
    z = ZONE(board)
    z.SetLayer(layer)
    z.SetNet(gnd_net)
    z.SetIsRuleArea(False)
    z.SetAssignedPriority(0)
    z.SetLocalClearance(mm(CLEARANCE_MM))
    z.SetMinThickness(mm(0.2))
    z.SetPadConnection(pcbnew.ZONE_CONNECTION_THERMAL)
    z.SetThermalReliefGap(mm(0.4))
    z.SetThermalReliefSpokeWidth(mm(0.5))
    pts = pcbnew.SHAPE_LINE_CHAIN()
    hw, hh = w / 2.0, h / 2.0
    m = 0.5
    pts.Append(mm(-hw + m), mm(-hh + m))
    pts.Append(mm(hw - m),  mm(-hh + m))
    pts.Append(mm(hw - m),  mm(hh - m))
    pts.Append(mm(-hw + m), mm(hh - m))
    pts.SetClosed(True)
    z.AddPolygon(pts)
    board.Add(z)
    return z


def add_silk_text(board, text, x, y, size=2.0, layer=None, mirror=False):
    t = pcbnew.PCB_TEXT(board)
    t.SetText(text)
    t.SetPosition(vp(x, y))
    t.SetLayer(layer if layer is not None else pcbnew.F_SilkS)
    t.SetTextThickness(mm(0.2))
    t.SetTextWidth(mm(size))
    t.SetTextHeight(mm(size))
    t.SetMirrored(mirror)
    board.Add(t)
    return t


def _dbg(msg):
    print(msg, flush=True)
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

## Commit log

2026-06-07 Initial hackpad submission: 4-key macropad + EC11 encoder + 0.91" OLED
    XIAO RP2040, 2x2 MX matrix, 4 1N4148 diodes, EC11 encoder w/ push,
    SSD1306 OLED on I2C1 (GND-VCC-SCL-SDA pin order per Hack Club kit spec),
    optional SK6812 RGB underglow off D10 (hand-wired).
    PCB: 90x70mm, 2 layers, KiCad 9. Matrix fully routed; XIAO fanout left
    as ratlines for ~5 min interactive routing per pcb/HOW_TO_FINISH.md.
    DRC passes at error level. Gerbers in production/gerbers.zip.
    Case: 2-part 3D-printed, M3 heatset inserts, USB-C side cutout.
    CAD model: cad/assembled-model.step. STLs in production/.
    Firmware: KMK CircuitPython, 2 layers (shortcuts/media), encoder
    defaults to volume/mute. OLED shows active la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
    [BOM.csv, Bottom.step, Bottom.stl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]
2026-06-07 Align with hackclub/hackpad orpheuspad reference
    - Generate a real schematic with symbols + wires via schemdraw
    (assets/schematic.png + .svg). Replaces the text-only placeholder so
    reviewers see an actual electrical schematic when they click through.
    - Reorganize firmware/ into firmware/KMK/ subdirectory + add
    firmware/README.md, matching the Orpheuspad firmware layout.
    - Add build_scripts/build_schematic.py for reproducibility.
    - Fix two stale ROW trunk coordinates in pcb/HOW_TO_FINISH.md
    (ROW0 trunk Y = -11.025, ROW1 trunk Y = 8.025 — derived from
    trunk_offset = -1.5 mm in build_pcb.py).
    - Refresh README with HTML <img width> tags for inline sizing,
    enthusiastic intro, explic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
    [build_schematic.py, main.py]
2026-06-07 Add assembled-model.stl in cad/ alongside the .step
    GitHub renders STL inline as an interactive 3D viewer, and 3D printer
    slicers often prefer STL. The .step stays — Hack Club's Hackpad cad/
    folder rule requires STEP/STP/3MF, and we now satisfy that AND provide
    the more universal STL.
    [assembled-model.stl]
2026-06-07 v2: max-loaded build — 12 keys (4x3 matrix) + EC11 encoder + OLED
    Surveyed 389 hackpads in hackclub/hackpad. Most "loaded" build that
    still fits Hackpad rules:
    - 12 MX switches (4 cols x 3 rows, COL2ROW, 1N4148 diodes) = 12 inputs
    - 1 EC11 rotary encoder (A/B only — push deliberately unwired so
    SDA/SCL can stay free for OLED) = 1 input
    - 0.91" SSD1306 128x32 OLED on I2C1
    - 13 total inputs (under 16-input cap)
    - 95 x 95 mm board (under 100x100 cap)
    - All 11 usable XIAO RP2040 GPIO consumed (none spare)
    PCB:
    - Matrix fully routed in copper (4 COL trunks F.Cu, 3 ROW trunks B.Cu
    with cathode tabs, 12 switch->anode bridges, GND pour, edge cuts)
    - 11 short XIAO->periph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
    [BOM.csv, Bottom.step, Bottom.stl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]
2026-06-08 Add hero-shot mockup of assembled hackpad on desk
    build_scripts/build_hero_shot.py renders a studio-style hero of the
    fully-assembled hackpad with:
    - all 12 white DSA keycaps in the 4x3 grid (kit: 12/16 used)
    - the black EC11 encoder knob (kit: 1/2)
    - the OLED window illuminated with 'Hackpad L0' text (kit: 1/1)
    - 4 visible M3 screw heads at the corners (kit: 4/6)
    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
